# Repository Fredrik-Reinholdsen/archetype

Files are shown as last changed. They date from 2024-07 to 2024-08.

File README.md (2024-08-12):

# Archetype

A compact System on Module (SOM) for audio processing and DSP.
It features 6-layer, 5x3 cm PCB, a powerful 550 MHz STM32H7 micro-controller with additional peripherals such as a high fidelity audio CODEC,
SDRAM and flash memory.

The board has two mezzanine connectors on the back, one for analog signals and one for digital.
Many of the STM32 peripherals are wired to and accesible via the mezzanine connectors, including SPI, I2C, UART, CAN, ADC inputs.

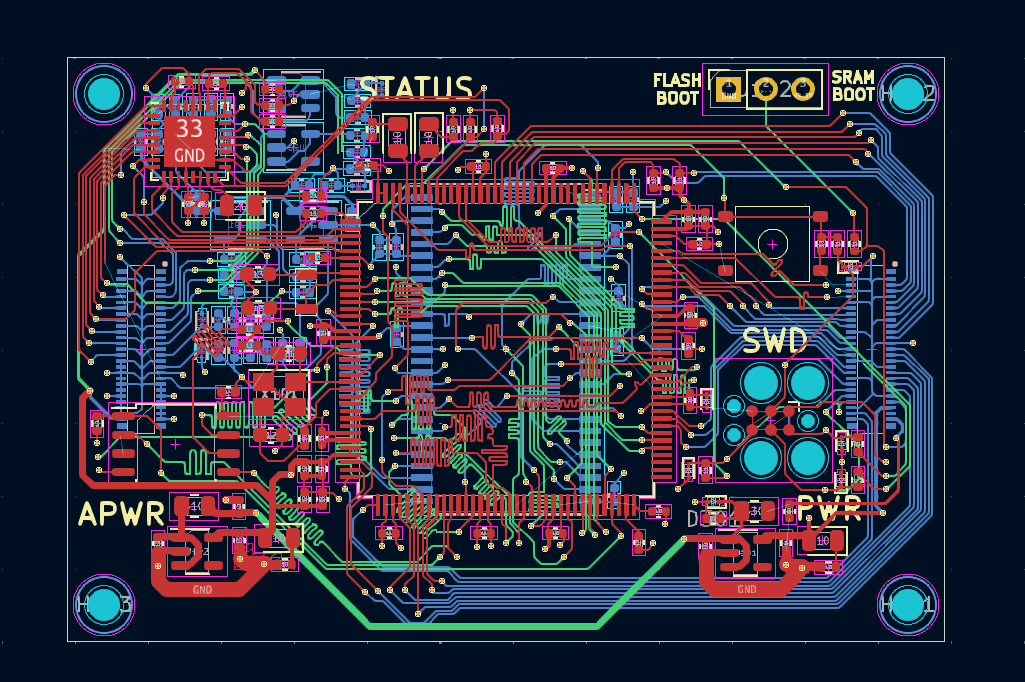
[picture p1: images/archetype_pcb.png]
Archetype PCB


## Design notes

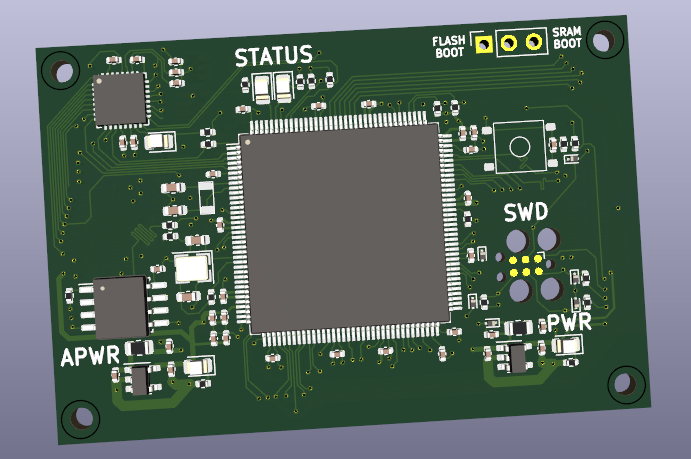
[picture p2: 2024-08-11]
images/archetype_3dmodel.png

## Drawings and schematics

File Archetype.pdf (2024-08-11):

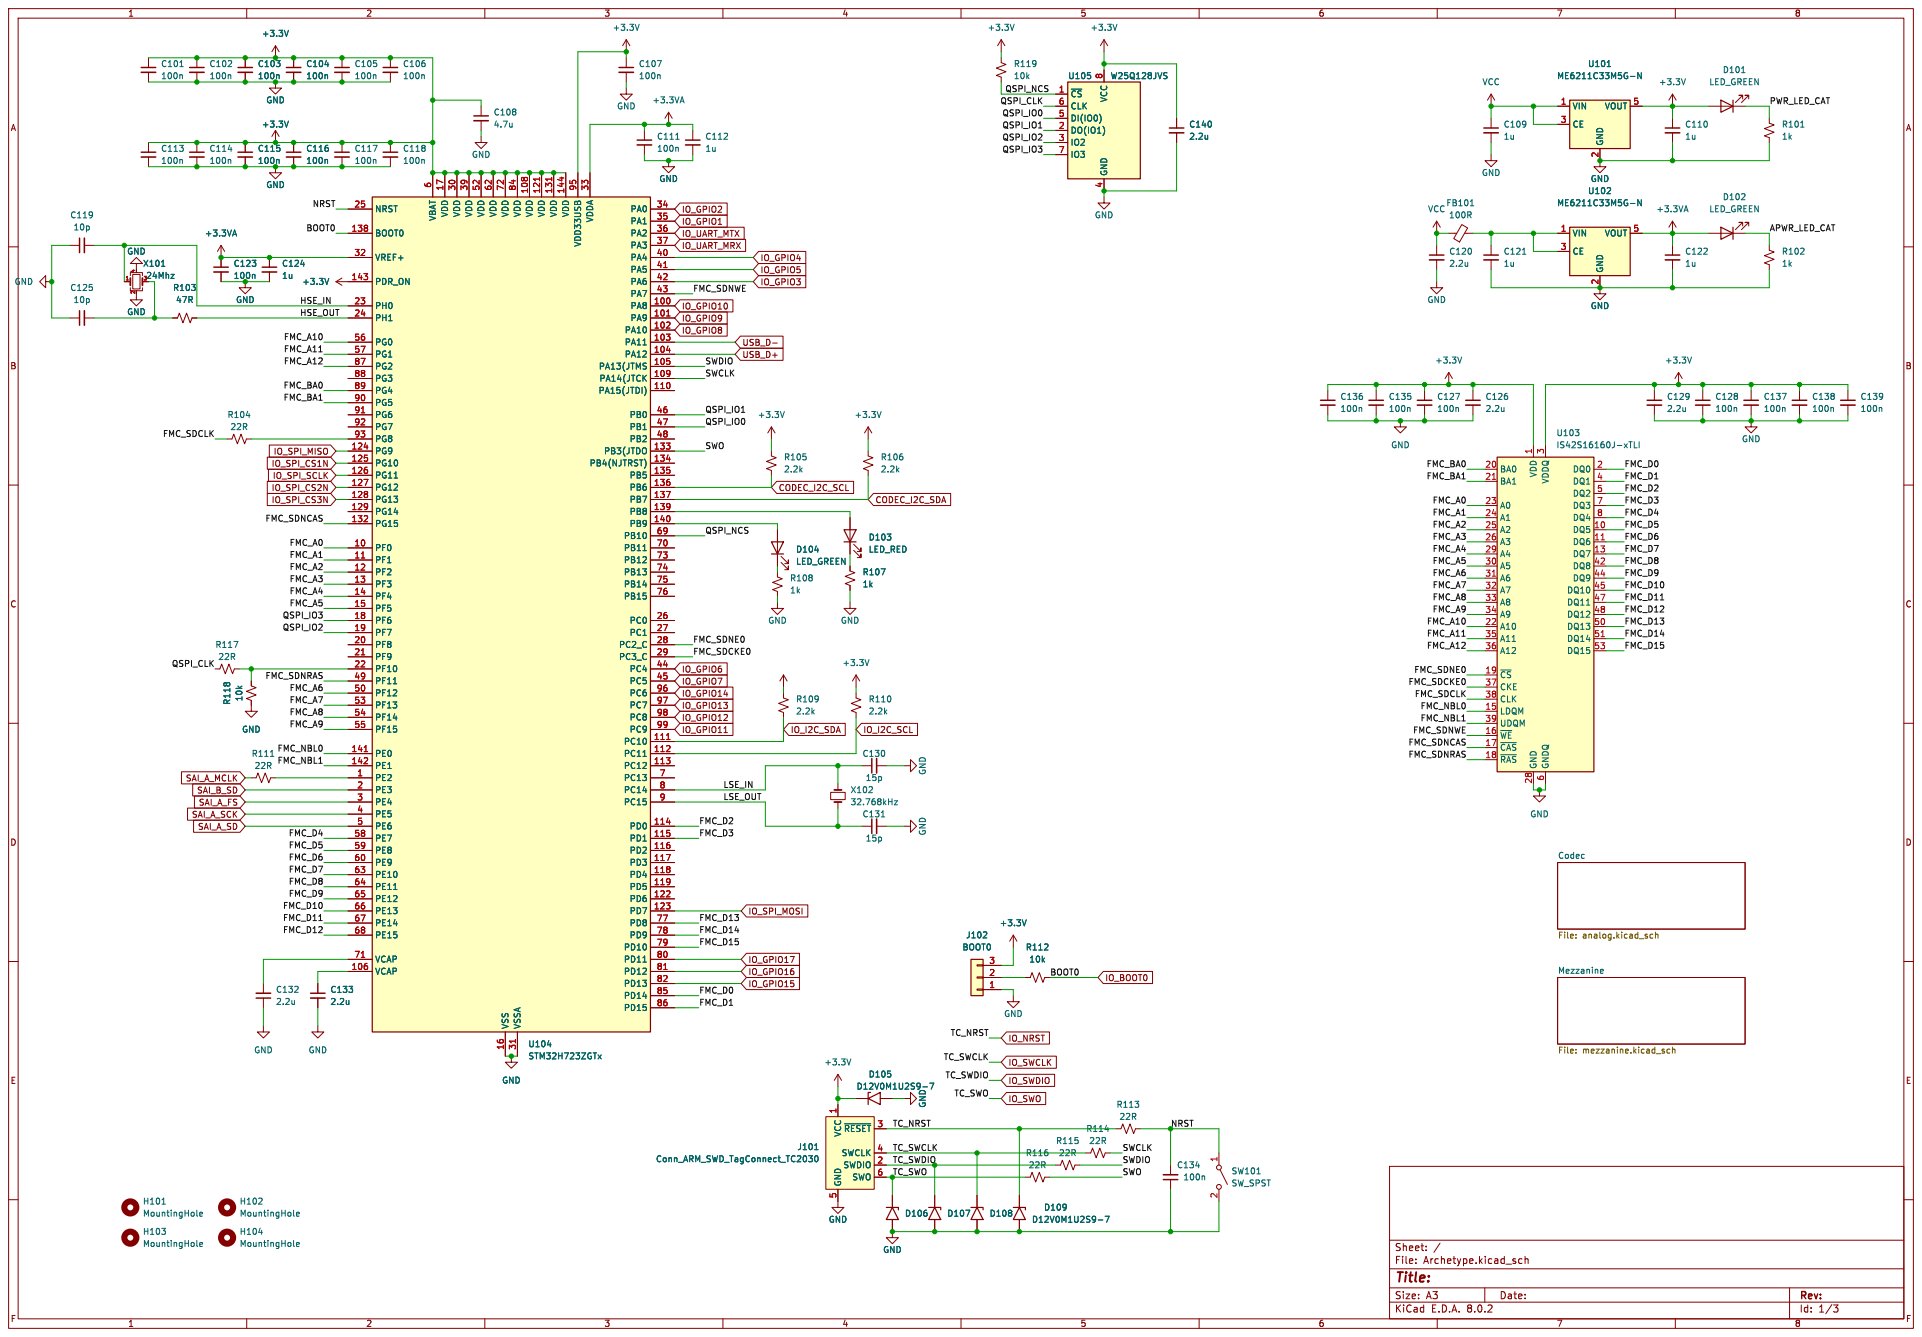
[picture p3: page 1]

2 CE 3 VOUT 5 U101 ME6211C33M5G-N GND VCC

3 A5 30 A6 31 A7 32 A8 33 A9 34 A11 35 A12 36 CKE 37 CLK 38 UDQM 39 DQ1 4 DQ8 42 DQ9 44 DQ10 45 DQ11 47 DQ12 48 DQ2 5 DQ13 50 DQ14 51 DQ15 53 GNDQ

1 SWDIO 2 ~{RESET}3 SWCLK 4 GND

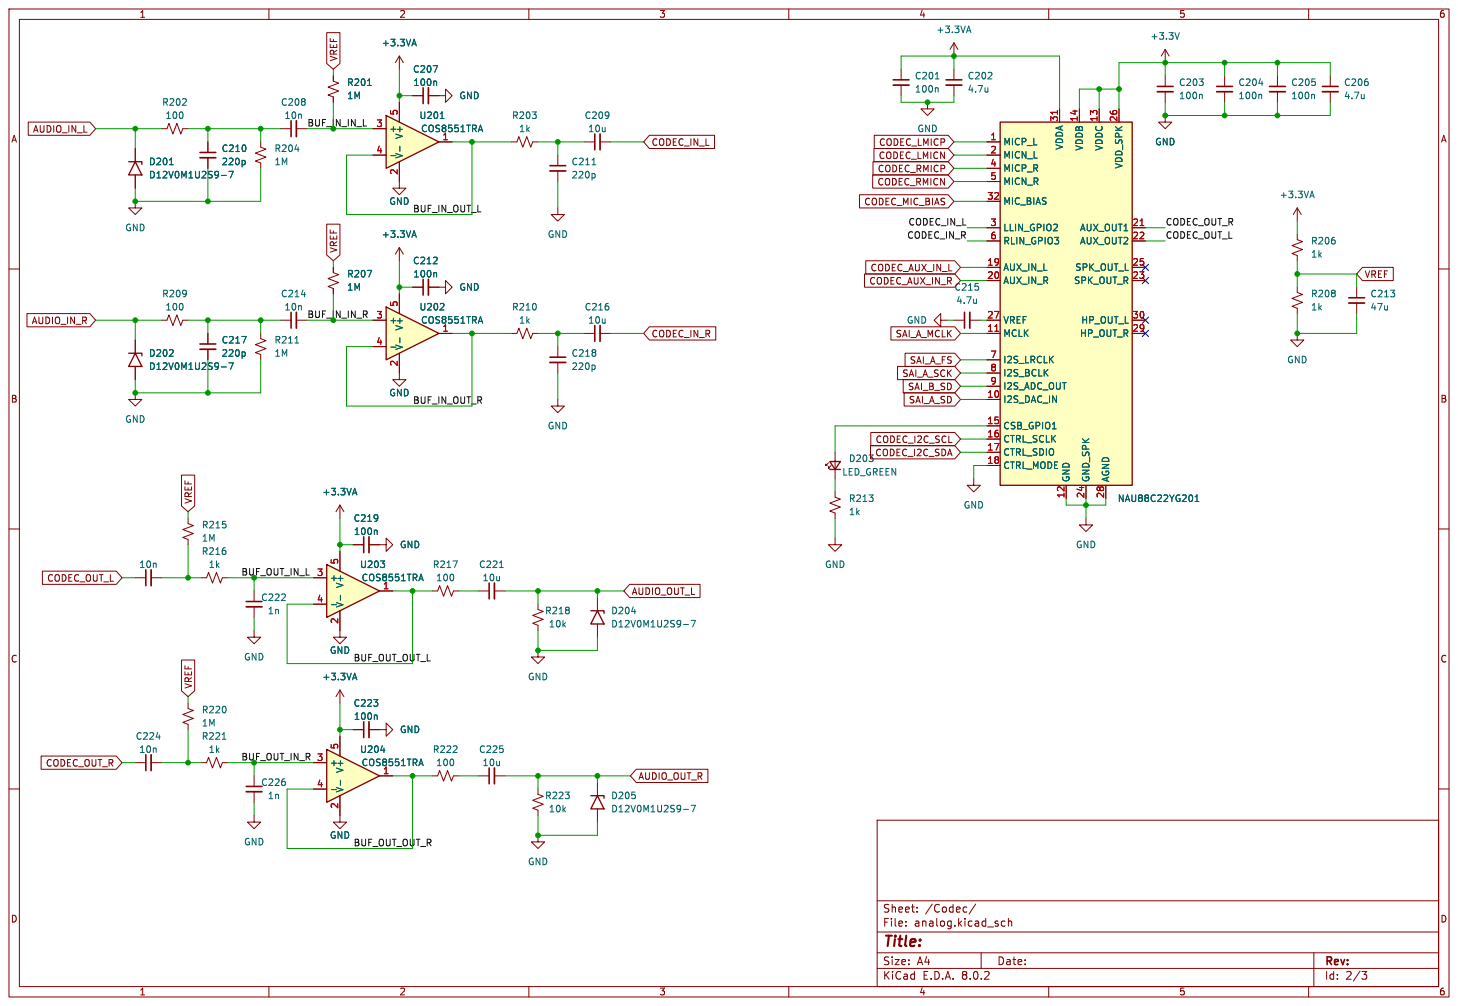
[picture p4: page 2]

Id: 2/3 Title: File: analog.kicad_sch Sheet: /Codec/ R216

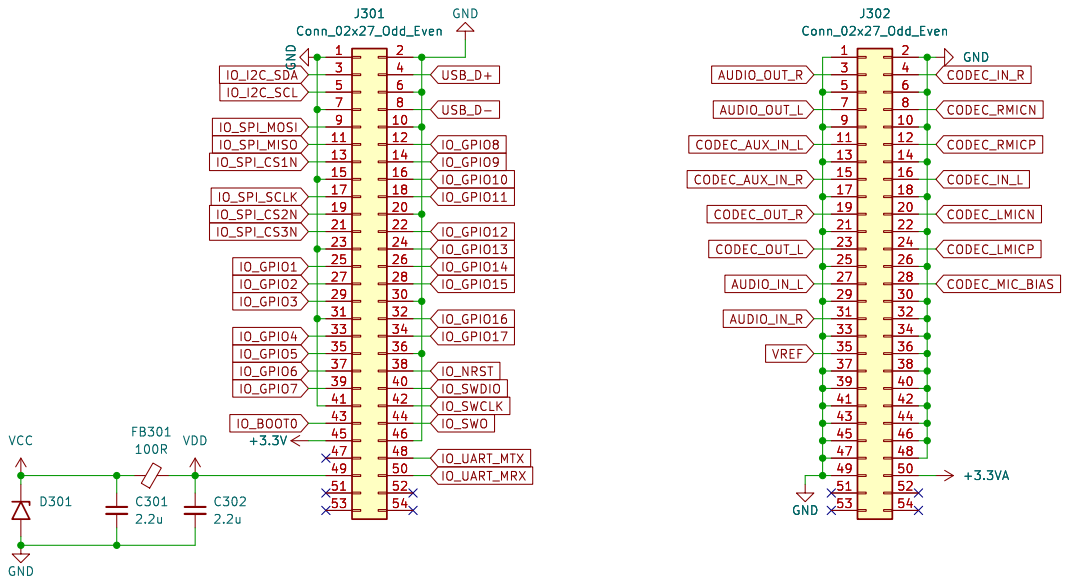
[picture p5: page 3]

Id: 3/3 Title: File: mezzanine.kicad_sch Sheet: /Mezzanine/

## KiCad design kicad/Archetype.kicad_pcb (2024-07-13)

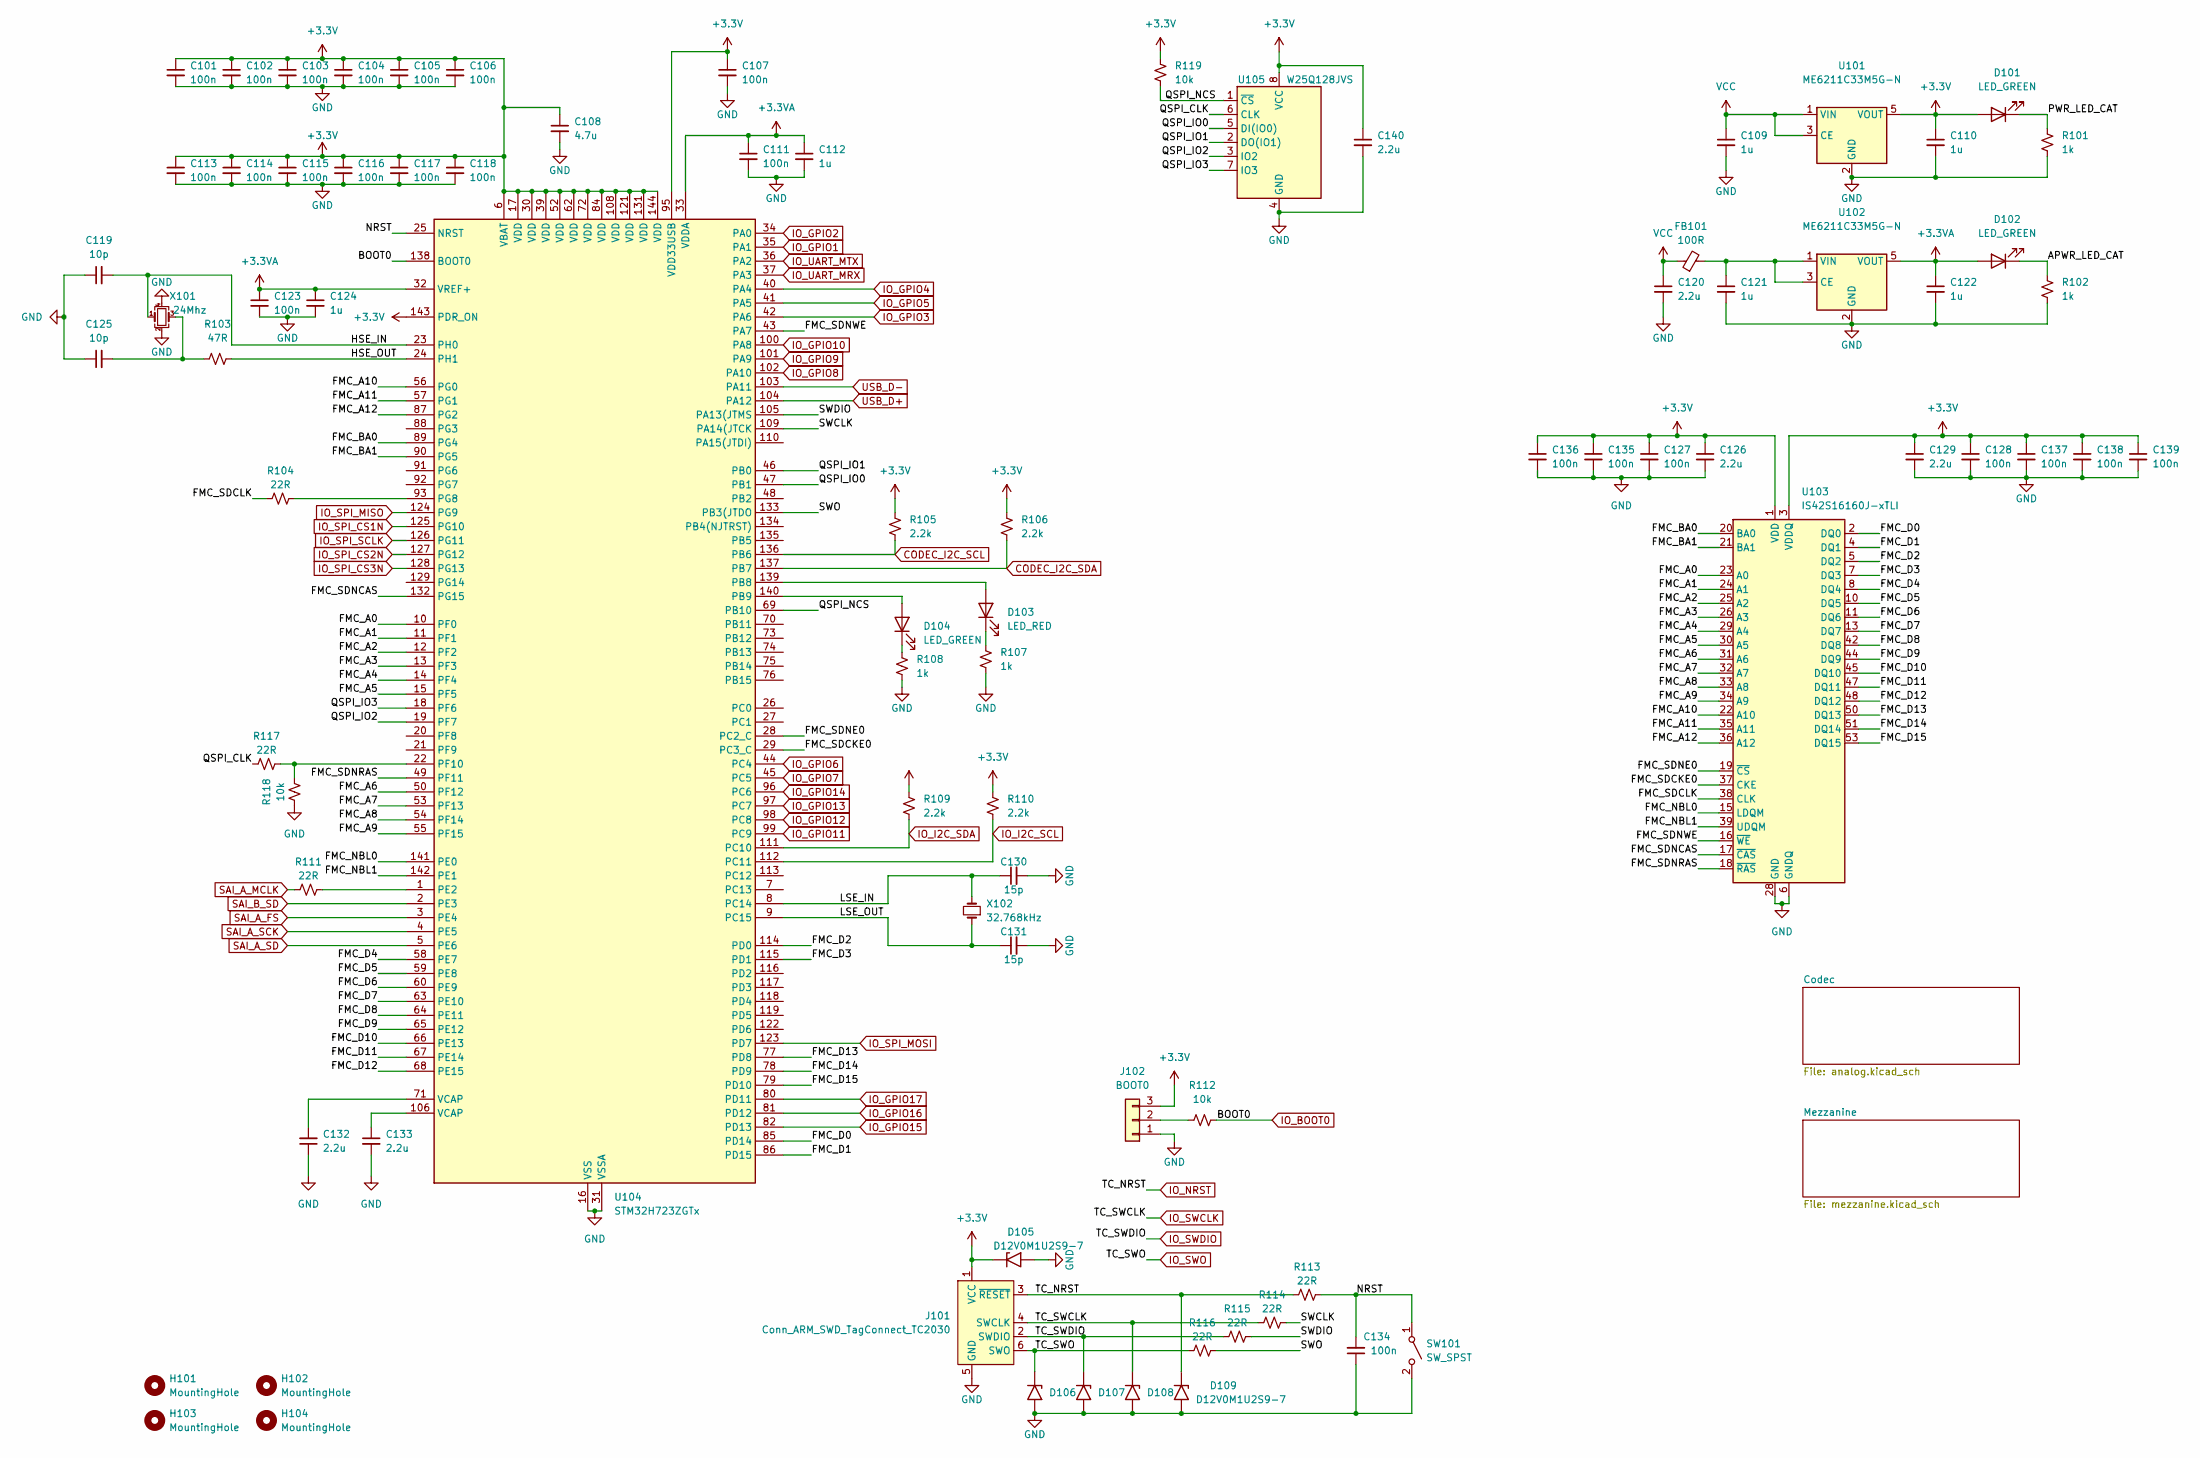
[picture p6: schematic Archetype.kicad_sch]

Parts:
C101, C102, C103, C104, C105, C106, C107, C111, C113, C114, C115, C116, C117, C118, C123, C127, C128, C134, C135, C136, C137, C138, C139: 100n; C_0402_1005Metric
C108: 4.7u; C_0402_1005Metric
C109, C110, C112, C121, C122, C124: 1u; C_0402_1005Metric
C119, C125: 10p; C_0603_1608Metric
C120, C126, C129, C132, C133, C140: 2.2u; C_0402_1005Metric
C130, C131: 15p; C_0603_1608Metric
D101, D102, D104: LED_GREEN; LED_0805_2012Metric
D103: LED_RED; LED_0805_2012Metric
D105, D106, D107, D108, D109: D12V0M1U2S9-7; D_SOD-923
FB101: 100R; R_0805_2012Metric
H101, H102, H103, H104: MountingHole; MountingHole_2.2mm_M2_DIN965
J101: Conn_ARM_SWD_TagConnect_TC2030; Tag-Connect_TC2030-IDC-FP_2x03_P1.27mm_Vertical
J102: BOOT0; PinSocket_1x03_P2.54mm_Vertical
R101, R102, R107, R108: 1k; R_0402_1005Metric
R103: 47R; R_0402_1005Metric
R104, R111, R113, R114, R115, R116, R117: 22R; R_0402_1005Metric
R105, R106, R109, R110: 2.2k; R_0402_1005Metric
R112, R118, R119: 10k; R_0402_1005Metric
SW101: SW_SPST; SPST_TS-1187A-B-A-B
U101, U102: ME6211C33M5G-N; SOT-23-5
U103: IS42S16160J-xTLI; TSOP-II-54_22.2x10.16mm_P0.8mm
U104: STM32H723ZGTx; LQFP-144_20x20mm_P0.5mm
U105: W25Q128JVS; SOIC-8_5.23x5.23mm_P1.27mm
X101: 24Mhz; Crystal_SMD_3225-4Pin_3.2x2.5mm
X102: 32.768kHz; SMD_3215-2Pin

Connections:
+3.3V: C101.1, C102.1, C103.1, C104.1, C105.1, C106.1, C107.1, C108.1, C110.1, C113.1, C114.1, C115.1, C116.1, C117.1, C118.1, C126.1, C127.1, C128.1, C129.1, C135.1, C136.1, C137.1, C138.1, C139.1, C140.1, D101.2 (A), D105.1 (A1), J101.1 (VCC), J102.3, R105.1, R106.1, R109.1, R110.1, R119.1, U101.5 (VOUT), U103.1 (VDD), U103.3 (VDDQ), U103.9 (VDDQ), U103.14 (VDD), U103.27 (VDD), U103.43 (VDDQ), U103.49 (VDDQ), U104.6 (VBAT), U104.17 (VDD), U104.30 (VDD), U104.39 (VDD), U104.52 (VDD), U104.62 (VDD), U104.72 (VDD), U104.84 (VDD), U104.95 (VDD33USB), U104.108 (VDD), U104.121 (VDD), U104.131 (VDD), U104.143 (PDR_ON), U104.144 (VDD), U105.8 (VCC); also elsewhere on the board
+3.3VA: C111.1, C112.1, C122.1, C123.1, C124.1, D102.2 (A), U102.5 (VOUT), U104.32 (VREF+), U104.33 (VDDA); also elsewhere on the board
/APWR_LED_CAT: D102.1 (K), R102.1
/FMC_A0: U103.23 (A0), U104.10 (PF0)
/FMC_A1: U103.24 (A1), U104.11 (PF1)
/FMC_A2: U103.25 (A2), U104.12 (PF2)
/FMC_A3: U103.26 (A3), U104.13 (PF3)
/FMC_A4: U103.29 (A4), U104.14 (PF4)
/FMC_A5: U103.30 (A5), U104.15 (PF5)
/FMC_A6: U103.31 (A6), U104.50 (PF12)
/FMC_A7: U103.32 (A7), U104.53 (PF13)
/FMC_A8: U103.33 (A8), U104.54 (PF14)
/FMC_A9: U103.34 (A9), U104.55 (PF15)
/FMC_A10: U103.22 (A10), U104.56 (PG0)
/FMC_A11: U103.35 (A11), U104.57 (PG1)
/FMC_A12: U103.36 (A12), U104.87 (PG2)
/FMC_BA0: U103.20 (BA0), U104.89 (PG4)
/FMC_BA1: U103.21 (BA1), U104.90 (PG5)
/FMC_D0: U103.2 (DQ0), U104.85 (PD14)
/FMC_D1: U103.4 (DQ1), U104.86 (PD15)
/FMC_D2: U103.5 (DQ2), U104.114 (PD0)
/FMC_D3: U103.7 (DQ3), U104.115 (PD1)
/FMC_D4: U103.8 (DQ4), U104.58 (PE7)
/FMC_D5: U103.10 (DQ5), U104.59 (PE8)
/FMC_D6: U103.11 (DQ6), U104.60 (PE9)
/FMC_D7: U103.13 (DQ7), U104.63 (PE10)
/FMC_D8: U103.42 (DQ8), U104.64 (PE11)
/FMC_D9: U103.44 (DQ9), U104.65 (PE12)
/FMC_D10: U103.45 (DQ10), U104.66 (PE13)
/FMC_D11: U103.47 (DQ11), U104.67 (PE14)
/FMC_D12: U103.48 (DQ12), U104.68 (PE15)
/FMC_D13: U103.50 (DQ13), U104.77 (PD8)
/FMC_D14: U103.51 (DQ14), U104.78 (PD9)
/FMC_D15: U103.53 (DQ15), U104.79 (PD10)
/FMC_NBL0: U103.15 (LDQM), U104.141 (PE0)
/FMC_NBL1: U103.39 (UDQM), U104.142 (PE1)
/FMC_SDCKE0: U103.37 (CKE), U104.29 (PC3_C)
/FMC_SDCLK: R104.2, U103.38 (CLK)
/FMC_SDNCAS: U103.17 (~CAS), U104.132 (PG15)
/FMC_SDNE0: U103.19 (~CS), U104.28 (PC2_C)
/FMC_SDNRAS: U103.18 (~RAS), U104.49 (PF11)
/FMC_SDNWE: U103.16 (~WE), U104.43 (PA7)
/HSE_IN: C119.2, U104.23 (PH0), X101.1
/HSE_OUT: R103.1, U104.24 (PH1)
/LSE_IN: C130.1, U104.8 (PC14), X102.2
/LSE_OUT: C131.1, U104.9 (PC15), X102.1
/NRST: C134.2, R113.2, SW101.1 (A), U104.25 (NRST)
/PWR_LED_CAT: D101.1 (K), R101.1
/QSPI_CLK: R117.2, U105.6 (CLK)
/QSPI_IO0: U104.47 (PB1), U105.5 (DI(IO0))
/QSPI_IO1: U104.46 (PB0), U105.2 (DO(IO1))
/QSPI_IO2: U104.19 (PF7), U105.3 (IO2)
/QSPI_IO3: U104.18 (PF6), U105.7 (IO3)
/QSPI_NCS: R119.2, U104.69 (PB10), U105.1 (~CS)
/SWCLK: R114.2, U104.109 (PA14(JTCK)
/SWDIO: R115.2, U104.105 (PA13(JTMS)
/SWO: R116.2, U104.133 (PB3(JTDO)
CODEC_I2C_SCL: R105.2, U104.136 (PB6); also elsewhere on the board
CODEC_I2C_SDA: R106.2, U104.137 (PB7); also elsewhere on the board
GND: C101.2, C102.2, C103.2, C104.2, C105.2, C106.2, C107.2, C108.2, C109.2, C110.2, C111.2, C112.2, C113.2, C114.2, C115.2, C116.2, C117.2, C118.2, C119.1, C120.2, C121.2, C122.2, C123.2, C124.2, C125.1, C126.2, C127.2, C128.2, C129.2, C130.2, C131.2, C132.1, C133.2, C134.1, C135.2, C136.2, C137.2, C138.2, C139.2, C140.2, D105.2 (A2), D106.2 (A2), D107.2 (A2), D108.2 (A2), D109.2 (A2), J101.5 (GND), J102.1, R101.2, R102.2, R107.2, R108.2, R118.2, SW101.2 (B), U101.2 (GND), U102.2 (GND), U103.6 (GNDQ), U103.12 (GNDQ), U103.28 (GND), U103.41 (GND), U103.46 (GNDQ), U103.52 (GNDQ), U103.54 (GND), U104.16 (VSS), U104.31 (VSSA), U104.38 (VSS), U104.51 (VSS), U104.61 (VSS), U104.83 (VSS), U104.94 (VSS), U104.107 (VSS), U104.120 (VSS), U104.130 (VSS), U105.4 (GND), X101.2, X101.4; also elsewhere on the board
IO_BOOT0: R112.2, U104.138 (BOOT0); also elsewhere on the board
IO_GPIO1: U104.35 (PA1); also elsewhere on the board
IO_GPIO2: U104.34 (PA0); also elsewhere on the board
IO_GPIO3: U104.42 (PA6); also elsewhere on the board
IO_GPIO4: U104.40 (PA4); also elsewhere on the board
IO_GPIO5: U104.41 (PA5); also elsewhere on the board
IO_GPIO6: U104.44 (PC4); also elsewhere on the board
IO_GPIO7: U104.45 (PC5); also elsewhere on the board
IO_GPIO8: U104.102 (PA10); also elsewhere on the board
IO_GPIO9: U104.101 (PA9); also elsewhere on the board
IO_GPIO10: U104.100 (PA8); also elsewhere on the board
IO_GPIO11: U104.99 (PC9); also elsewhere on the board
IO_GPIO12: U104.98 (PC8); also elsewhere on the board
IO_GPIO13: U104.97 (PC7); also elsewhere on the board
IO_GPIO14: U104.96 (PC6); also elsewhere on the board
IO_GPIO15: U104.82 (PD13); also elsewhere on the board
IO_GPIO16: U104.81 (PD12); also elsewhere on the board
IO_GPIO17: U104.80 (PD11); also elsewhere on the board
IO_I2C_SCL: R110.2, U104.112 (PC11); also elsewhere on the board
IO_I2C_SDA: R109.2, U104.111 (PC10); also elsewhere on the board
IO_NRST: D109.1 (A1), J101.3 (~RESET), R113.1; also elsewhere on the board
IO_SPI_CS1N: U104.125 (PG10); also elsewhere on the board
IO_SPI_CS2N: U104.127 (PG12); also elsewhere on the board
IO_SPI_CS3N: U104.128 (PG13); also elsewhere on the board
IO_SPI_MISO: U104.124 (PG9); also elsewhere on the board
IO_SPI_MOSI: U104.123 (PD7); also elsewhere on the board
IO_SPI_SCLK: U104.126 (PG11); also elsewhere on the board
IO_SWCLK: D108.1 (A1), J101.4 (SWCLK), R114.1; also elsewhere on the board
IO_SWDIO: D107.1 (A1), J101.2 (SWDIO), R115.1; also elsewhere on the board
IO_SWO: D106.1 (A1), J101.6 (SWO), R116.1; also elsewhere on the board
IO_UART_MRX: U104.37 (PA3); also elsewhere on the board
IO_UART_MTX: U104.36 (PA2); also elsewhere on the board
unnamed: C125.2, R103.2, X101.3
unnamed: C132.2, U104.71 (VCAP)
unnamed: C133.1, U104.106 (VCAP)
unnamed: D103.2 (A), U104.139 (PB8)
unnamed: D103.1 (K), R107.1
unnamed: D104.2 (A), U104.140 (PB9)
unnamed: D104.1 (K), R108.1
unnamed: J102.2, R112.1
unnamed: C121.1, FB101.2, U102.1 (VIN), U102.3 (CE)
unnamed: R111.1, U104.1 (PE2)
unnamed: R117.1, R118.1, U104.22 (PF10)
unnamed: R104.1, U104.93 (PG8)
SAI_A_FS: U104.3 (PE4); also elsewhere on the board
SAI_A_MCLK: R111.2; also elsewhere on the board
SAI_A_SCK: U104.4 (PE5); also elsewhere on the board
SAI_A_SD: U104.5 (PE6); also elsewhere on the board
SAI_B_SD: U104.2 (PE3); also elsewhere on the board
USB_D+: U104.104 (PA12); also elsewhere on the board
USB_D-: U104.103 (PA11); also elsewhere on the board
VCC: C109.1, C120.1, FB101.1, U101.1 (VIN), U101.3 (CE); also elsewhere on the board

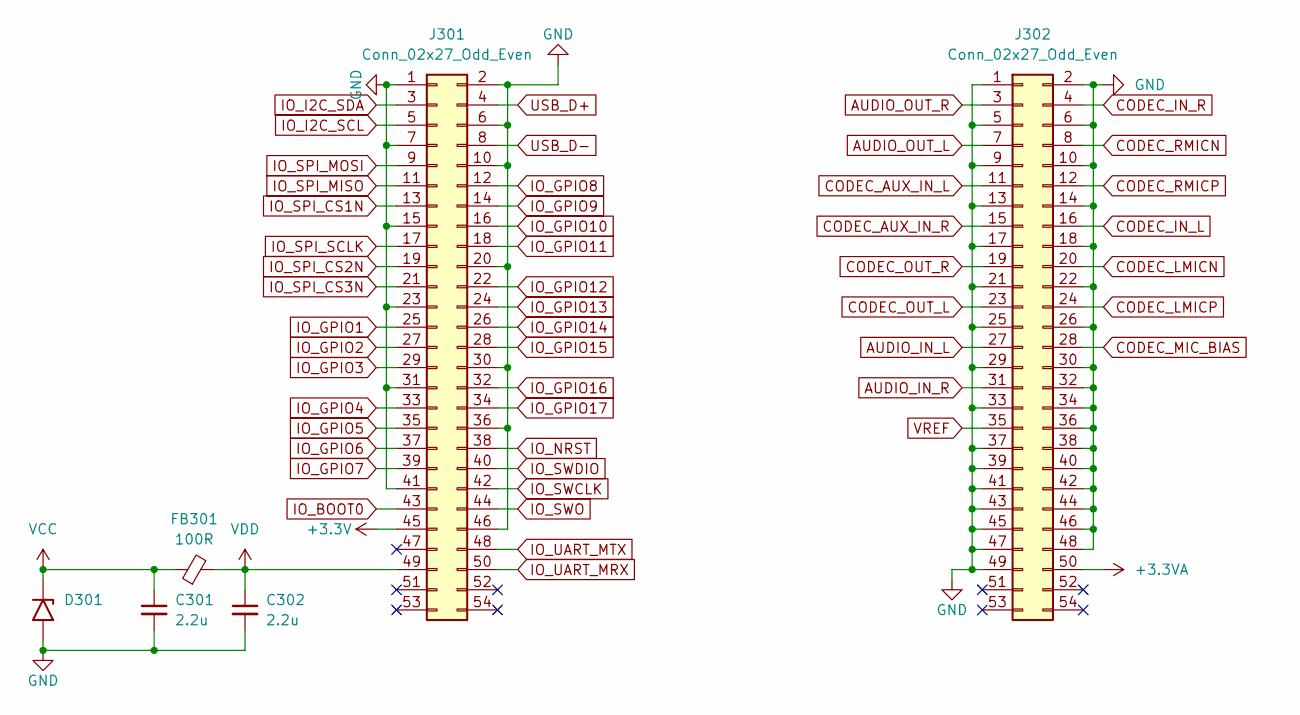
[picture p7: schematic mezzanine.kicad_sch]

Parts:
C301, C302: 2.2u; C_0402_1005Metric
D301: D12V0M1U2S9-7; D_SOD-923
FB301: 100R; R_0805_2012Metric
J301, J302: Conn_02x27_Odd_Even; DF40C-50DP-0.4V

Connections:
+3.3V: J301.45; also elsewhere on the board
+3.3VA: J302.50; also elsewhere on the board
AUDIO_IN_L: J302.27; also elsewhere on the board
AUDIO_IN_R: J302.31; also elsewhere on the board
AUDIO_OUT_L: J302.7; also elsewhere on the board
AUDIO_OUT_R: J302.3; also elsewhere on the board
CODEC_AUX_IN_L: J302.11; also elsewhere on the board
CODEC_AUX_IN_R: J302.15; also elsewhere on the board
CODEC_IN_L: J302.16; also elsewhere on the board
CODEC_IN_R: J302.4; also elsewhere on the board
CODEC_LMICN: J302.20; also elsewhere on the board
CODEC_LMICP: J302.24; also elsewhere on the board
CODEC_MIC_BIAS: J302.28; also elsewhere on the board
CODEC_OUT_L: J302.23; also elsewhere on the board
CODEC_OUT_R: J302.19; also elsewhere on the board
CODEC_RMICN: J302.8; also elsewhere on the board
CODEC_RMICP: J302.12; also elsewhere on the board
GND: C301.2, C302.2, D301.2 (A2), J301.1, J301.2, J301.6, J301.7, J301.10, J301.15, J301.20, J301.23, J301.30, J301.31, J301.36, J301.41, J301.46, J302.1, J302.2, J302.5, J302.6, J302.9, J302.10, J302.13, J302.14, J302.17, J302.18, J302.21, J302.22, J302.25, J302.26, J302.29, J302.30, J302.32, J302.33, J302.34, J302.36, J302.37, J302.38, J302.39, J302.40, J302.41, J302.42, J302.43, J302.44, J302.45, J302.46, J302.47, J302.48, J302.49; also elsewhere on the board
IO_BOOT0: J301.43; also elsewhere on the board
IO_GPIO1: J301.25; also elsewhere on the board
IO_GPIO2: J301.27; also elsewhere on the board
IO_GPIO3: J301.29; also elsewhere on the board
IO_GPIO4: J301.33; also elsewhere on the board
IO_GPIO5: J301.35; also elsewhere on the board
IO_GPIO6: J301.37; also elsewhere on the board
IO_GPIO7: J301.39; also elsewhere on the board
IO_GPIO8: J301.12; also elsewhere on the board
IO_GPIO9: J301.14; also elsewhere on the board
IO_GPIO10: J301.16; also elsewhere on the board
IO_GPIO11: J301.18; also elsewhere on the board
IO_GPIO12: J301.22; also elsewhere on the board
IO_GPIO13: J301.24; also elsewhere on the board
IO_GPIO14: J301.26; also elsewhere on the board
IO_GPIO15: J301.28; also elsewhere on the board
IO_GPIO16: J301.32; also elsewhere on the board
IO_GPIO17: J301.34; also elsewhere on the board
IO_I2C_SCL: J301.5; also elsewhere on the board
IO_I2C_SDA: J301.3; also elsewhere on the board
IO_NRST: J301.38; also elsewhere on the board
IO_SPI_CS1N: J301.13; also elsewhere on the board
IO_SPI_CS2N: J301.19; also elsewhere on the board
IO_SPI_CS3N: J301.21; also elsewhere on the board
IO_SPI_MISO: J301.11; also elsewhere on the board
IO_SPI_MOSI: J301.9; also elsewhere on the board
IO_SPI_SCLK: J301.17; also elsewhere on the board
IO_SWCLK: J301.42; also elsewhere on the board
IO_SWDIO: J301.40; also elsewhere on the board
IO_SWO: J301.44; also elsewhere on the board
IO_UART_MRX: J301.50; also elsewhere on the board
IO_UART_MTX: J301.48; also elsewhere on the board
USB_D+: J301.4; also elsewhere on the board
USB_D-: J301.8; also elsewhere on the board
VCC: C301.1, D301.1 (A1), FB301.1; also elsewhere on the board
VDD: C302.1, FB301.2, J301.49
VREF: J302.35; also elsewhere on the board

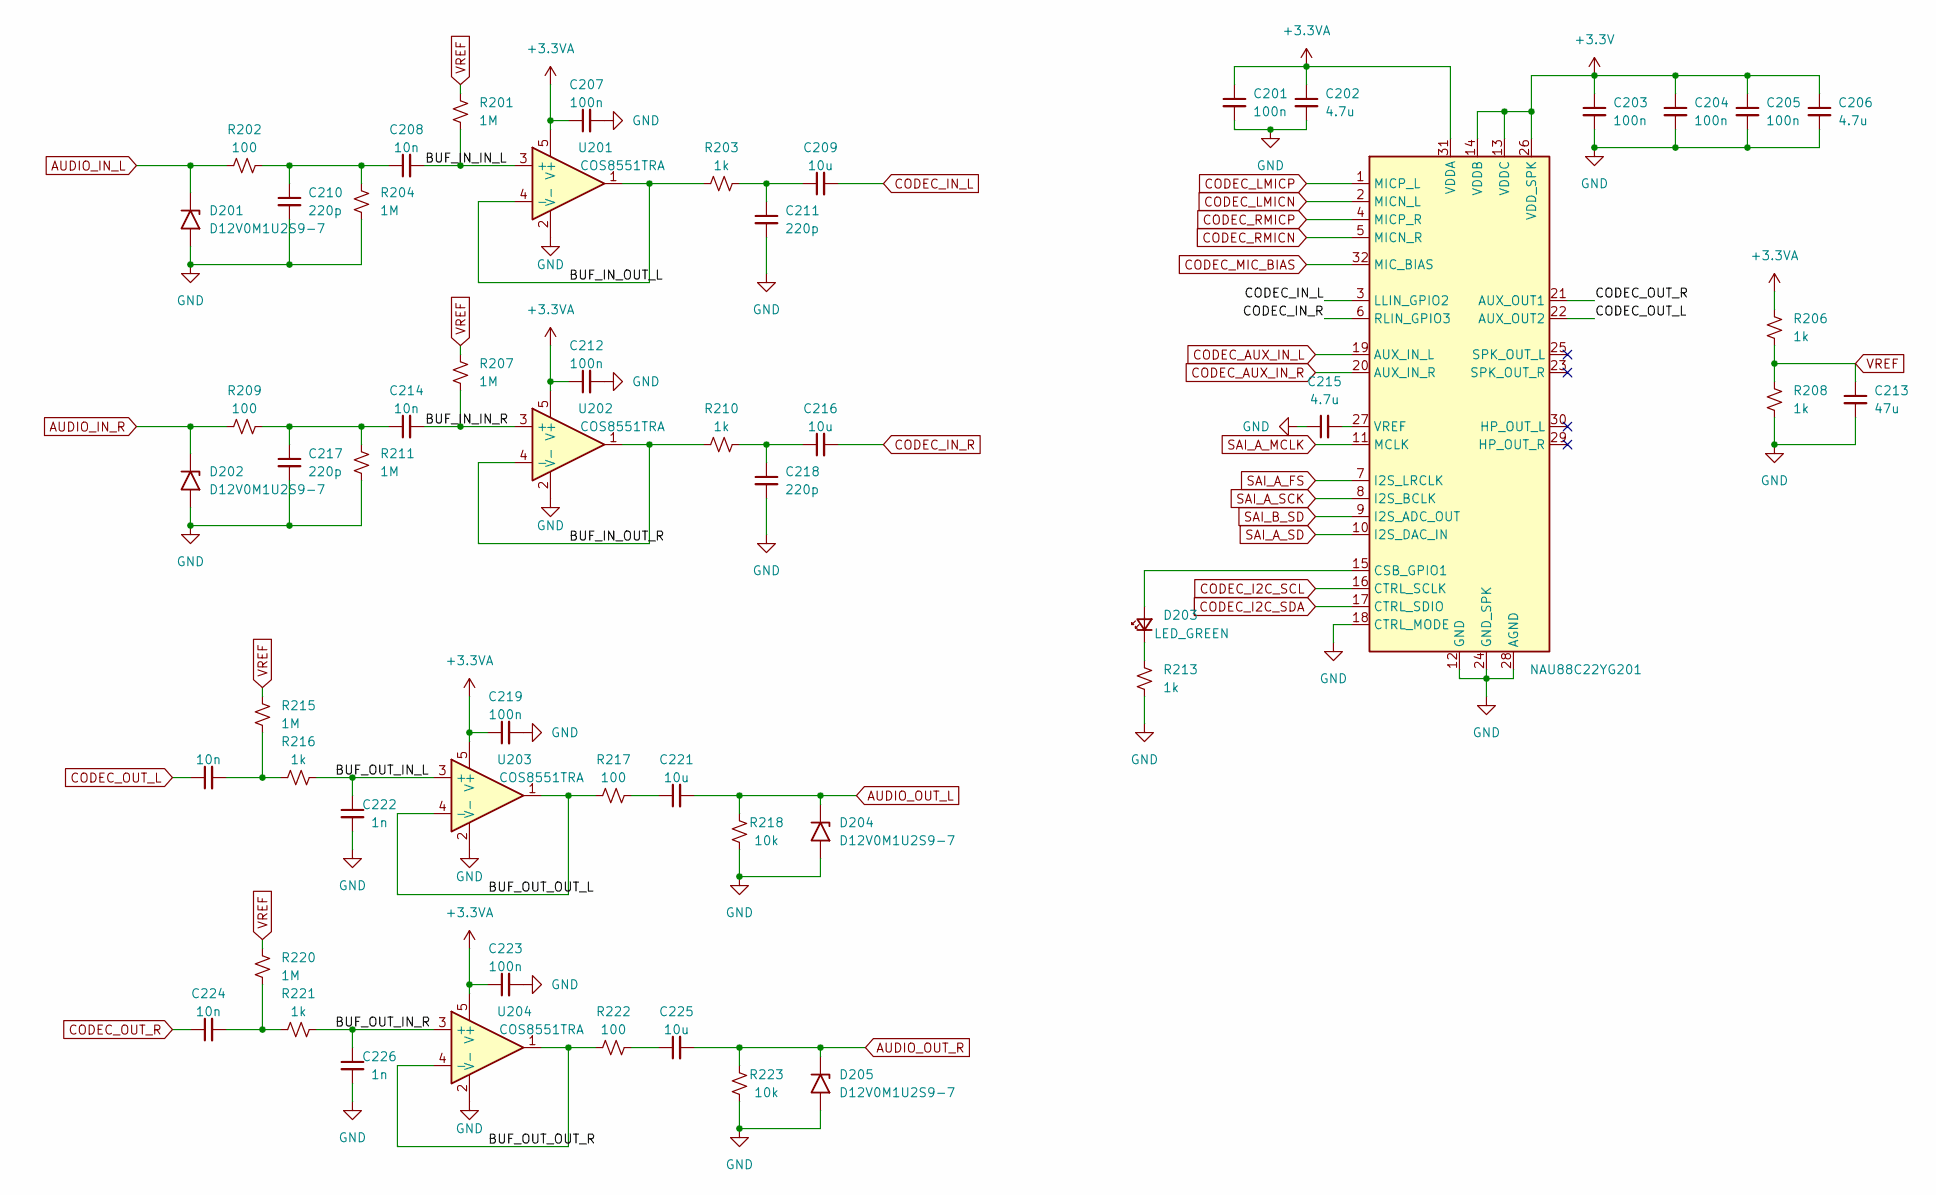
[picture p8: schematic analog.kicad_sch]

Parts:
C201, C203, C204, C205, C207, C212, C219, C223: 100n; C_0402_1005Metric
C202, C206, C215: 4.7u; C_0402_1005Metric
C208, C214, C220, C224: 10n; C_0402_1005Metric
C209, C216, C221, C225: 10u; C_0402_1005Metric
C210, C211, C217, C218: 220p; C_0402_1005Metric
C213: 47u; C_0402_1005Metric
C222, C226: 1n; C_0402_1005Metric
D201, D202, D204, D205: D12V0M1U2S9-7; D_SOD-923
D203: LED_GREEN; LED_0805_2012Metric
NAU88C22YG201: VQFN-32-1EP_5x5mm_P0.5mm_EP3.5x3.5mm
R201, R204, R207, R211, R215, R220: 1M; R_0402_1005Metric
R202, R209, R217, R222: 100; R_0402_1005Metric
R203, R206, R208, R210, R213, R216, R221: 1k; R_0402_1005Metric
R218, R223: 10k; R_0402_1005Metric
U201, U202, U203, U204: COS8551TRA; SOT-23-5

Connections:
+3.3V: C203.1, C204.1, C205.1, C206.1, NAU88C22YG201.13 (VDDC), NAU88C22YG201.14 (VDDB), NAU88C22YG201.26 (VDD_SPK); also elsewhere on the board
+3.3VA: C201.1, C202.1, C207.1, C212.1, C219.1, C223.1, NAU88C22YG201.31 (VDDA), R206.2, U201.5 (V+), U202.5 (V+), U203.5 (V+), U204.5 (V+); also elsewhere on the board
/Codec/BUF_IN_IN_L: C208.2, R201.1, U201.3 (+)
/Codec/BUF_IN_IN_R: C214.2, R207.1, U202.3 (+)
/Codec/BUF_IN_OUT_L: R203.2, U201.1, U201.4 (-)
/Codec/BUF_IN_OUT_R: R210.2, U202.1, U202.4 (-)
/Codec/BUF_OUT_IN_L: C222.1, R216.1, U203.3 (+)
/Codec/BUF_OUT_IN_R: C226.1, R221.1, U204.3 (+)
/Codec/BUF_OUT_OUT_L: R217.2, U203.1, U203.4 (-)
/Codec/BUF_OUT_OUT_R: R222.2, U204.1, U204.4 (-)
AUDIO_IN_L: D201.1 (A1), R202.1; also elsewhere on the board
AUDIO_IN_R: D202.1 (A1), R209.1; also elsewhere on the board
AUDIO_OUT_L: C221.2, D204.1 (A1), R218.2; also elsewhere on the board
AUDIO_OUT_R: C225.2, D205.1 (A1), R223.2; also elsewhere on the board
CODEC_AUX_IN_L: NAU88C22YG201.19 (AUX_IN_L); also elsewhere on the board
CODEC_AUX_IN_R: NAU88C22YG201.20 (AUX_IN_R); also elsewhere on the board
CODEC_I2C_SCL: NAU88C22YG201.16 (CTRL_SCLK); also elsewhere on the board
CODEC_I2C_SDA: NAU88C22YG201.17 (CTRL_SDIO); also elsewhere on the board
CODEC_IN_L: C209.2, NAU88C22YG201.3 (LLIN_GPIO2); also elsewhere on the board
CODEC_IN_R: C216.2, NAU88C22YG201.6 (RLIN_GPIO3); also elsewhere on the board
CODEC_LMICN: NAU88C22YG201.2 (MICN_L); also elsewhere on the board
CODEC_LMICP: NAU88C22YG201.1 (MICP_L); also elsewhere on the board
CODEC_MIC_BIAS: NAU88C22YG201.32 (MIC_BIAS); also elsewhere on the board
CODEC_OUT_L: C220.1, NAU88C22YG201.22 (AUX_OUT2); also elsewhere on the board
CODEC_OUT_R: C224.1, NAU88C22YG201.21 (AUX_OUT1); also elsewhere on the board
CODEC_RMICN: NAU88C22YG201.5 (MICN_R); also elsewhere on the board
CODEC_RMICP: NAU88C22YG201.4 (MICP_R); also elsewhere on the board
GND: C201.2, C202.2, C203.2, C204.2, C205.2, C206.2, C207.2, C210.2, C211.2, C212.2, C213.2, C215.1, C217.2, C218.2, C219.2, C222.2, C223.2, C226.2, D201.2 (A2), D202.2 (A2), D204.2 (A2), D205.2 (A2), NAU88C22YG201.12 (GND), NAU88C22YG201.18 (CTRL_MODE), NAU88C22YG201.24 (GND_SPK), NAU88C22YG201.28 (AGND), NAU88C22YG201.33 (GND), R204.1, R208.1, R211.1, R213.2, R218.1, R223.1, U201.2 (V-), U202.2 (V-), U203.2 (V-), U204.2 (V-); also elsewhere on the board
unnamed: C208.1, C210.1, R202.2, R204.2
unnamed: C209.1, C211.1, R203.1
unnamed: C214.1, C217.1, R209.2, R211.2
unnamed: C216.1, C218.1, R210.1
unnamed: C220.2, R215.1, R216.2
unnamed: C221.1, R217.1
unnamed: C224.2, R220.1, R221.2
unnamed: C225.1, R222.1
unnamed: D203.2 (A), NAU88C22YG201.15 (CSB_GPIO1)
unnamed: D203.1 (K), R213.1
unnamed: C215.2, NAU88C22YG201.27 (VREF)
SAI_A_FS: NAU88C22YG201.7 (I2S_LRCLK); also elsewhere on the board
SAI_A_MCLK: NAU88C22YG201.11 (MCLK); also elsewhere on the board
SAI_A_SCK: NAU88C22YG201.8 (I2S_BCLK); also elsewhere on the board
SAI_A_SD: NAU88C22YG201.10 (I2S_DAC_IN); also elsewhere on the board
SAI_B_SD: NAU88C22YG201.9 (I2S_ADC_OUT); also elsewhere on the board
VREF: C213.1, R201.2, R206.1, R207.2, R208.2, R215.2, R220.2; also elsewhere on the board

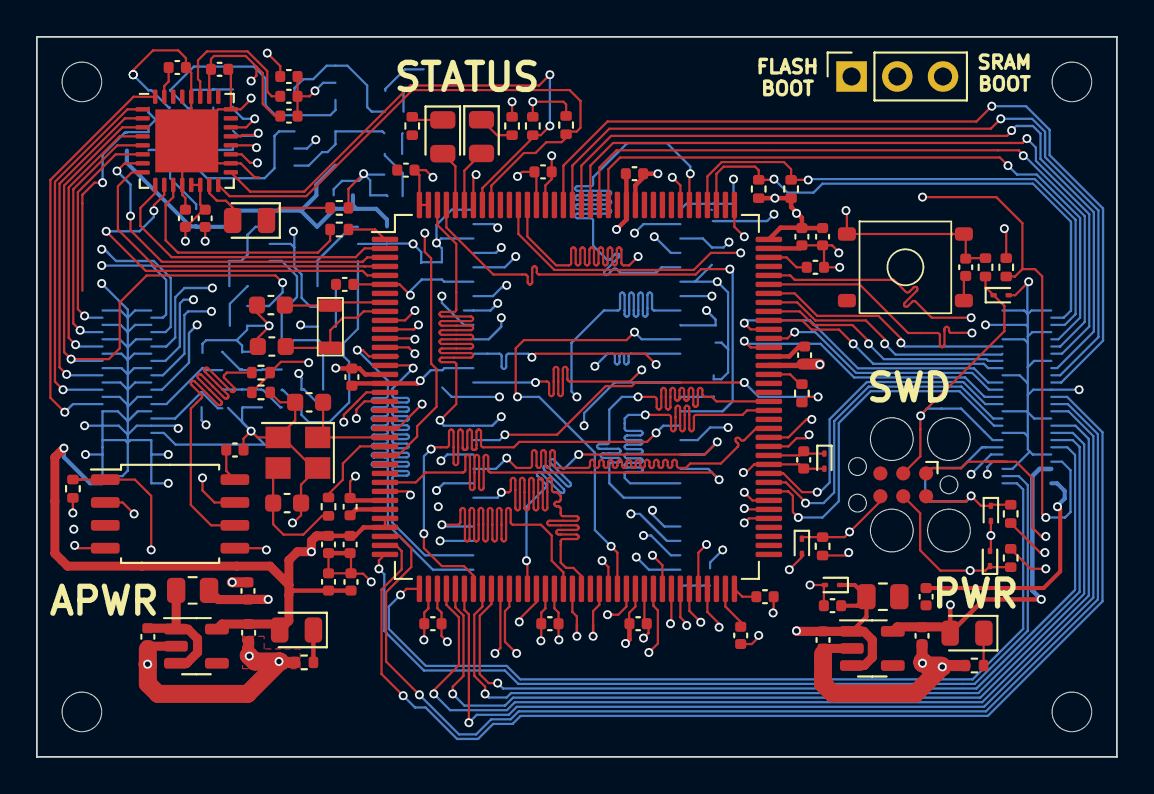
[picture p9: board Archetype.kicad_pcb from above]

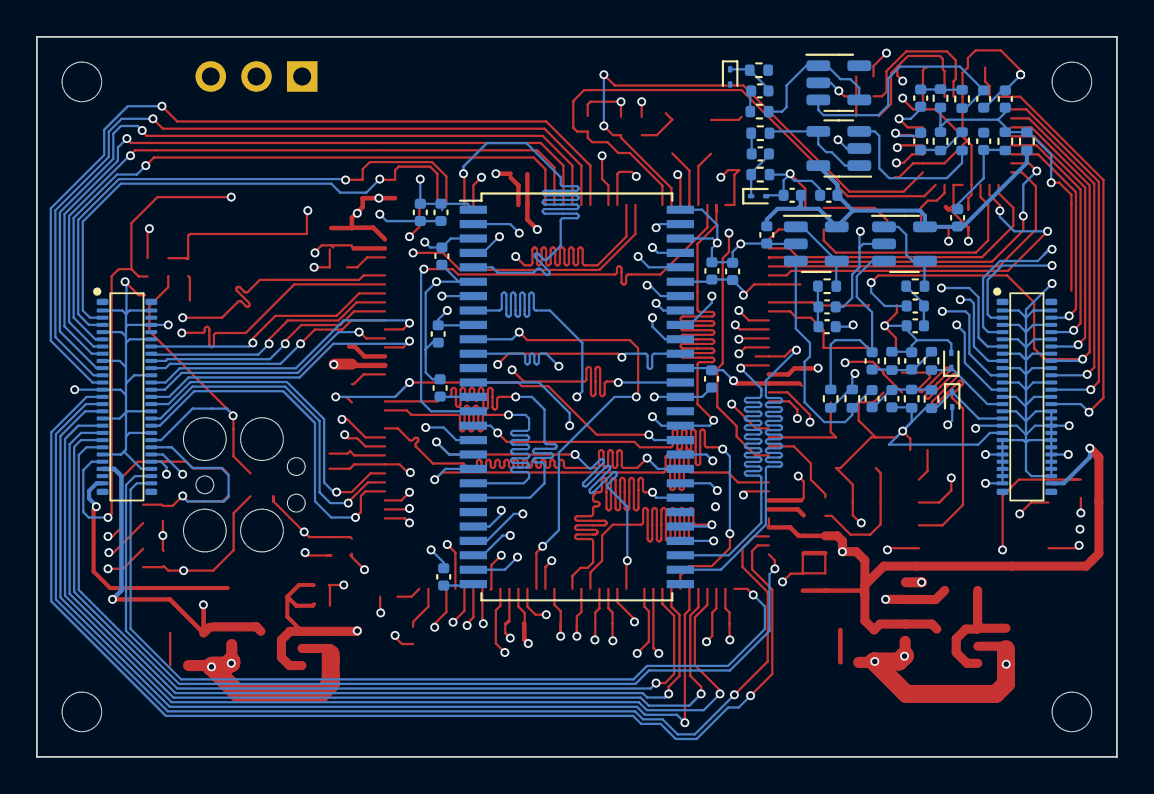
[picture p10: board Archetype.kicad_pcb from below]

Board: 6 copper layers, 60.0 x 40.0 mm, 144 parts (57 on the bottom side), 148 nets.

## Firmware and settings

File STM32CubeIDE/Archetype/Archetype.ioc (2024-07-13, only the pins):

Mcu.UserName=STM32H723ZGTx
PA11.Signal=USB_OTG_HS_DM
PA12.Signal=USB_OTG_HS_DP
PA13(JTMS/SWDIO).Signal=DEBUG_JTMS-SWDIO
PA14(JTCK/SWCLK).Signal=DEBUG_JTCK-SWCLK
PA2.Signal=USART2_TX
PA3.Signal=USART2_RX
PA4.Signal=ADCx_INP18
PA5.Signal=ADCx_INP19
PA6.Signal=ADCx_INP3
PA7.Signal=FMC_SDNWE
PB0.Signal=OCTOSPIM_P1_IO1
PB1.Signal=OCTOSPIM_P1_IO0
PB10.Signal=OCTOSPIM_P1_NCS
PB3(JTDO/TRACESWO).Signal=DEBUG_JTDO-SWO
PB6.Signal=I2C1_SCL
PB7.Signal=I2C1_SDA
PC10.Signal=I2C5_SDA
PC11.Signal=I2C5_SCL
PC14-OSC32_IN.Signal=RCC_OSC32_IN
PC15-OSC32_OUT.Signal=RCC_OSC32_OUT
PC2_C.Signal=FMC_SDNE0
PC3_C.Signal=FMC_SDCKE0
PC4.Signal=ADCx_INP4
PC5.Signal=ADCx_INP8
PC6.Signal=S_TIM3_CH1
PC7.Signal=S_TIM3_CH2
PD0.Signal=FMC_D2_DA2
PD1.Signal=FMC_D3_DA3
PD10.Signal=FMC_D15_DA15
PD12.Signal=FDCAN3_RX
PD13.Signal=FDCAN3_TX
PD14.Signal=FMC_D0_DA0
PD15.Signal=FMC_D1_DA1
PD7.Signal=SPI1_MOSI
PD8.Signal=FMC_D13_DA13
PD9.Signal=FMC_D14_DA14
PE0.Signal=FMC_NBL0
PE1.Signal=FMC_NBL1
PE10.Signal=FMC_D7_DA7
PE11.Signal=FMC_D8_DA8
PE12.Signal=FMC_D9_DA9
PE13.Signal=FMC_D10_DA10
PE14.Signal=FMC_D11_DA11
PE15.Signal=FMC_D12_DA12
PE2.Signal=SAI1_MCLK_A
PE3.Signal=SAI1_SD_B
PE4.Signal=SAI1_FS_A
PE5.Signal=SAI1_SCK_A
PE6.Signal=SAI1_SD_A
PE7.Signal=FMC_D4_DA4
PE8.Signal=FMC_D5_DA5
PE9.Signal=FMC_D6_DA6
PF0.Signal=FMC_A0
PF1.Signal=FMC_A1
PF10.Signal=OCTOSPIM_P1_CLK
PF11.Signal=FMC_SDNRAS
PF12.Signal=FMC_A6
PF13.Signal=FMC_A7
PF14.Signal=FMC_A8
PF15.Signal=FMC_A9
PF2.Signal=FMC_A2
PF3.Signal=FMC_A3
PF4.Signal=FMC_A4
PF5.Signal=FMC_A5
PF6.Signal=OCTOSPIM_P1_IO3
PF7.Signal=OCTOSPIM_P1_IO2
PF8.Signal=SAI1_SCK_B
PF9.Signal=SAI1_FS_B
PG0.Signal=FMC_A10
PG1.Signal=FMC_A11
PG10.Signal=SPI1_NSS
PG11.Signal=SPI1_SCK
PG12.Signal=GPIO_Output
PG13.Signal=GPIO_Output
PG15.Signal=FMC_SDNCAS
PG2.Signal=FMC_A12
PG4.Signal=FMC_A14_BA0
PG5.Signal=FMC_A15_BA1
PG8.Signal=FMC_SDCLK
PG9.Signal=SPI1_MISO
PH0-OSC_IN.Signal=RCC_OSC_IN
PH1-OSC_OUT.Signal=RCC_OSC_OUT
